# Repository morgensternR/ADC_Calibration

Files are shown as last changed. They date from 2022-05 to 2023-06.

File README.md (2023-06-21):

# ADC_Calibration
Collection/file history in making the ADC calibration board

 Copyright 2023 Ryan Morgenstern

   Licensed under the Apache License, Version 2.0 (the "License");
   you may not use this file except in compliance with the License.
   You may obtain a copy of the License at

       http://www.apache.org/licenses/LICENSE-2.0

   Unless required by applicable law or agreed to in writing, software
   distributed under the License is distributed on an "AS IS" BASIS,
   WITHOUT WARRANTIES OR CONDITIONS OF ANY KIND, either express or implied.
   See the License for the specific language governing permissions and
   limitations under the License.

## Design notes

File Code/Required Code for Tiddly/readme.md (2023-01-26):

Code for Microcontroller: 
adc_cali_board.py
diode_cali.py
MCP3421.py

Code for PC IDE:
agilent_34411a.py
Main_program.py

These Instructions assume you are following the TiddlyWiki as a reference, other hardware or Python IDE ( or no IDE) can be used to accomplish
the same task however these instructions may not assist you with that. Good Luck

Instructions:
1. Upload adc_cali_board.py, diode_cali.py, MCP3421.py to the QTPY2040. 
2. The program to run on the microcontroller is diode_cali.py (it will import the other two files you uploaded).
3. If using a python IDE (I used spyder), make sure agilent_34411a.py and Main_program.py are located in the same folder. 
	if an error occurs running the script (such as can't find import), make sure to set the console working directory to be the same as Main_program.py 
	(EX: With Main_progam.py opened in spyder, right click the top tab labeled with the file name and click 'set console working directory)
	You may also need to change the COM port...Either use device manager on windows or check it in Thonny when you connect the device...
4. Assuming everything is wired correctly for taking a short measurement, run short_measure() in Main_program.py. This will output 3 (4 outputs) measurements. 
	[[ADC integer, ADC Voltage], DMM voltage, DMM voltage reversed polarity]. 
5. Assuming everything is wired correctly for to the ADC_Calibrator board.
	Input previous short_measure() values into Calibrate(first DMM reading, second dmm reading, adc integer, and adc voltage). Run code.
6. Output format is [adc_array, dmm_0,dmm_1, dmm_c, pre_diff, post_diff, voltage, lin_info]

Explanation of output format:

adc_array = ADC integer & voltage output (non-corrected)

dmm_0 = DMM measurement of short or resistor

dmm_1 = DMM measurement of short or resistor reversed polarity

dmm_c = corrected DMM measurement without offsets ( abs(dmm_0) + abs(dmm_1) ) / 2 = dmm_c

lin_info = Linear fit to X axis being the dmm_c measurements, and Y axis is adc_array[adc integer]. We want the ADC's integer output to match the correct voltage.
	Contains slope and offset

voltage = slope and offset taken from lin_info using y = mx + b, adc_integer = adc_voltage_output * slope + offset. adc_voltage_output = (adc_int - offset)/slope

pre_diff = dmm_c - adc_array[voltage output], to see the difference a pre corrected

post_diff = dmm_c - voltage, to see the difference post corrected

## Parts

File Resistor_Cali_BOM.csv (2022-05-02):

Comment | Designator | Footprint | LCSC
Conn_Coaxial | J1 | Connector:SMA-TH_BWSMA-KE-Z001 | C496549
DB9_Female | J2 | Connector:DB9_ASSMANN | C75749
Conn_01x20_Female | J3,J4 | Connector_PinSocket_2.54mm:PinSocket_1x20_P2.54mm_Vertical
Conn_01x16_Female | J5 | Connector_PinHeader_2.54mm:PinHeader_1x16_P2.54mm_Vertical
Conn_01x01_Female | J6 | Connector_PinSocket_2.54mm:PinSocket_1x01_P2.54mm_Horizontal
1K_1% | R1,R2,R3,R4,R5,R6,R7,R15,R16,R19,R20,R21,R22,R23,R24,R25,R33,R34 | Resistor_SMD:R0603 | C234341
120K_0.1% | R10,R28 | Resistor_SMD:R0603 | C136959
130K_0.1% | R11,R29 | Resistor_SMD:R0603 | C705808
140K_0.1% | R12,R30 | Resistor_SMD:R0603 | C326761
150K_0.1% | R13,R31 | Resistor_SMD:150K_0.1 | C413715
160K_0.1% | R14,R32 | Resistor_SMD:160K_0.1 | C473318
180K_0.1% | R17,R35 | Resistor_SMD:180K_0.1 | C473319
200K_0.1% | R18,R36 | Resistor_SMD:R0603 | C394540
100K_0.1% | R8,R26 | Resistor_SMD:R0603 | C335088
110K_0.1% | R9,R27 | Resistor_SMD:R0603 | C326736
J2 | DB9_Female | DB9_ASSMANN | -63.575000 | -14.180000 | 270.000000 | top
KAQY212S | U1,U2,U3,U4,U5,U6,U7,U8,U9,U10,U11,U12,U13,U14,U15,U16,U17,U18 | Connector:SOP-4_L4.4-W4.0-P2.54-LS7.0-BL | C194898

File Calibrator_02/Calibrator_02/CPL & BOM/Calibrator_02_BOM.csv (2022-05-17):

Comment | Designator | Footprint | LCSC
1uF | C1 | Capacitor_SMD:C_0402_1005Metric | C77009
LED | D1,D2,D3,D4,D5,D6,D7,D8 | 0_Resistor_02:LED0603-RD | C125093
Conn_01x04 | J1,J6 | Connector_JST:JST_SH_SM04B-SRSS-TB_1x04-1MP_P1.00mm_Horizontal | C371571
DB9_Female_MountingHoles | J2 | 0_Resistor_02:DSUB-TH_DMR-9S | C141882
Conn_Coaxial | J3 | Connector_Coaxial:SMA_Amphenol_901-144_Vertical
Conn_01x01_Female | J5 | Connector_PinSocket_2.54mm:PinSocket_1x01_P2.54mm_Horizontal
Jumper | JP1 | Jumper:SolderJumper-2_P1.3mm_Open_RoundedPad1.0x1.5mm
AW9523BTQR | M1 | 0_Resistor_02:TQFN-24_L4.0-W4.0-P0.50-TL-EP | C148077
4.7K | R1,R2,R3 | Resistor_SMD:R_0805_2012Metric | C17673
95.3 1% | R10,R17,R18,R19,R20,R21,R22,R23 | Resistor_SMD:R_0201_0603Metric_Pad0.64x0.40mm_HandSolder | C218188
84.5 1% | R11,R12,R13,R14,R15,R16,R24,R25,R26,R27,R28,R29,R30,R31,R32,R33,R34,R35,R36,R37,R38,R39,R40,R41 | Resistor_SMD:R_0201_0603Metric_Pad0.64x0.40mm_HandSolder | C177824
120K_0.1% | R4 | Resistor_SMD:R_0603_1608Metric_Pad0.98x0.95mm_HandSolder | C136959
140K_0.1% | R5 | Resistor_SMD:R_0603_1608Metric_Pad0.98x0.95mm_HandSolder | C326761
160K_0.1% | R6 | Resistor_SMD:R_0805_2012Metric_Pad1.20x1.40mm_HandSolder | C473318
180K_0.1% | R7 | Resistor_SMD:R_0805_2012Metric_Pad1.20x1.40mm_HandSolder | C473319
100K_0.1% | R8 | Resistor_SMD:R_0603_1608Metric_Pad0.98x0.95mm_HandSolder | C335088
200K_0.1% | R9 | Resistor_SMD:R_0603_1608Metric_Pad0.98x0.95mm_HandSolder | C394540
KAQY214STLD | U1,U2,U3,U4,U5,U6,U7,U8,U9,U10,U11,U12,U13,U14,U15,U16,U17,U18,U19,U20,U21,U22,U23,U24,U25,U26,U27,U28,U29,U30,U31,U32 | 0_Resistor_02:SOP-4_L3.9-W4.4-P2.54-LS7.0-BR | C113331

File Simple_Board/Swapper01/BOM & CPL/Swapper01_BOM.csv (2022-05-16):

Comment | Designator | Footprint | LCSC
DB9_Female_MountingHoles | J1 | 0_Swapper01:DSUB-TH_DMR-9S | C141882
Conn_01x04 | J2 | Connector_JST:JST_SH_SM04B-SRSS-TB_1x04-1MP_P1.00mm_Horizontal
Jumper | JP1,JP2,JP3,JP4,JP5,JP6,JP7,JP8,JP9,JP10,JP11,JP12,JP13,JP14,JP15,JP16,JP17,JP18,JP19,JP20,JP21,JP22,JP23,JP24 | Jumper:SolderJumper-2_P1.3mm_Open_RoundedPad1.0x1.5mm
Jumper_3_Open | JP25,JP26,JP27,JP28 | Jumper:SolderJumper-3_P1.3mm_Open_Pad1.0x1.5mm
100K | R1 | Resistor_SMD:R_0603_1608Metric_Pad0.98x0.95mm_HandSolder | C335088
120K | R2 | Resistor_SMD:R_0603_1608Metric_Pad0.98x0.95mm_HandSolder | C136959
140K | R3 | Resistor_SMD:R_0603_1608Metric_Pad0.98x0.95mm_HandSolder | C326761
160K | R4 | Resistor_SMD:R_0805_2012Metric_Pad1.20x1.40mm_HandSolder | C473318
180K | R5 | Resistor_SMD:R_0805_2012Metric_Pad1.20x1.40mm_HandSolder | C473319
200K | R6 | Resistor_SMD:R_0603_1608Metric_Pad0.98x0.95mm_HandSolder | C394540

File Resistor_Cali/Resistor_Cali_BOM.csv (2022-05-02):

Id | Designator | Package | Quantity | Designation | Supplier and ref
1 | J1 | SMA-TH_BWSMA-KE-Z001 | 1 | Conn_Coaxial
2 | U16,U15,U7,U14,U6,U13,U18,U5,U12,U4,U17,U11,U3,U10,U9,U2,U8,U1 | SOP-4_L4.4-W4.0-P2.54-LS7.0-BL | 18 | KAQY212S
3 | R25,R24,R7,R23,R6,R22,R34,R5,R21,R4,R33,R20,R3,R19,R16,R2,R15,R1 | R0603 | 18 | 1K_1%
4 | R32,R14 | 160K_0.1 | 2 | 160K_0.1%
5 | R31,R13 | 150K_0.1 | 2 | 150K_0.1%
6 | R30,R12 | R0603 | 2 | 140K_0.1%
7 | R29,R11 | R0603 | 2 | 130K_0.1%
8 | R36,R18 | R0603 | 2 | 200K_0.1%
9 | R28,R10 | R0603 | 2 | 120K_0.1%
10 | R35,R17 | 180K_0.1 | 2 | 180K_0.1%
11 | R27,R9 | R0603 | 2 | 110K_0.1%
12 | R26,R8 | R0603 | 2 | 100K_0.1%
13 | J5 | PinHeader_1x16_P2.54mm_Vertical | 1 | Conn_01x16_Female
14 | J4,J3 | PinSocket_1x20_P2.54mm_Vertical | 2 | Conn_01x20_Female
15 | J2 | DB9_ASSMANN | 1 | DB9_Female
16 | J6 | PinSocket_1x01_P2.54mm_Horizontal | 1 | Conn_01x01_Female

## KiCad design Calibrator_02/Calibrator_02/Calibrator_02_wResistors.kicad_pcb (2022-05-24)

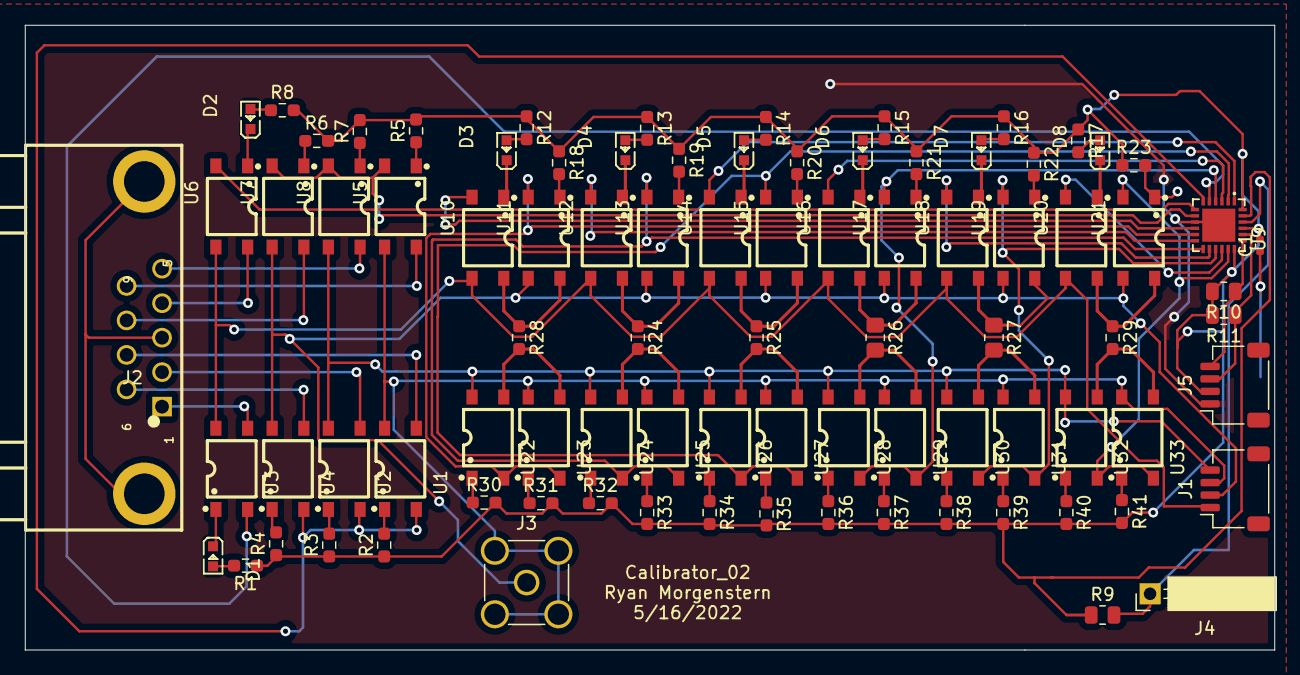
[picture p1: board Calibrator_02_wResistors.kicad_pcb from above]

Board: 2 copper layers, 100.0 x 50.0 mm, 88 parts (0 on the bottom side), 86 nets.

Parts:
C1: 100nF; C_0402_1005Metric
D1, D2, D3, D4, D5, D6, D7, D8: LED; LED0603-RD
J1, J5: Conn_01x04; JST_SH_SM04B-SRSS-TB_1x04-1MP_P1.00mm_Horizontal
J2: DB9_Female_MountingHoles; DSUB-TH_DMR-9S
J3: Conn_Coaxial; SMA_Amphenol_901-144_Vertical
J4: Conn_01x01_Female; PinSocket_1x01_P2.54mm_Horizontal
R1, R8, R12, R13, R14, R15, R16, R17: 95.3 1%; R_0603_1608Metric_Pad0.98x0.95mm_HandSolder
R2, R3, R4, R5, R6, R7, R18, R19, R20, R21, R22, R23, R30, R31, R32, R33, R34, R35, R36, R37, R38, R39, R40, R41: 84.5 1%; R_0603_1608Metric_Pad0.98x0.95mm_HandSolder
R9, R10, R11: 4.7K; R_0805_2012Metric
R24: 120K_0.1%; R_0603_1608Metric_Pad0.98x0.95mm_HandSolder
R25: 140K_0.1%; R_0603_1608Metric_Pad0.98x0.95mm_HandSolder
R26: 160K_0.1%; R_0805_2012Metric_Pad1.20x1.40mm_HandSolder
R27: 180K_0.1%; R_0805_2012Metric_Pad1.20x1.40mm_HandSolder
R28: 100K_0.1%; R_0603_1608Metric_Pad0.98x0.95mm_HandSolder
R29: 200K_0.1%; R_0603_1608Metric_Pad0.98x0.95mm_HandSolder
U1, U2, U3, U4, U5, U6, U7, U8, U10, U11, U12, U13, U14, U15, U16, U17, U18, U19, U20, U21, U22, U23, U24, U25, U26, U27, U28, U29, U30, U31, U32, U33: KAQY214STLD; SOP-4_L3.9-W4.4-P2.54-LS7.0-BR
U9: AW9523BTQR; TQFN-24_L4.0-W4.0-P0.50-TL-EP

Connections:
+3V3: C1.2, J5.2, R1.1, R2.1, R3.1, R4.1, R5.2, R6.2, R7.2, R8.2, R9.1, R10.2, R11.2, R12.1, R13.1, R14.1, R15.1, R16.1, R17.1, R18.1, R19.1, R20.1, R21.1, R22.1, R23.1, R30.2, R31.2, R32.2, R33.2, R34.2, R35.2, R36.2, R37.2, R38.2, R39.2, R40.2, R41.2, U9.18, U9.21, U9.23, U9.24
/I+: J2.1, U3.3
/I-: J2.2, U2.3
/I_00: U3.2, U9.5
/I_01: U1.2, U2.2, U4.2, U9.6
/I_02: U6.2, U9.7
/I_2+: J2.4, U6.4
/I_2-: J2.5, U8.4
/I_03: U5.2, U7.2, U8.2, U9.8
/I_04: U9.10, U10.2
/I_05: U9.11, U11.2, U22.2, U23.2
/I_06: U9.12, U12.2
/I_07: U9.13, U13.2, U24.2, U25.2
/I_10: U9.1, U14.2
/I_11: U9.2, U15.2, U26.2, U27.2
/I_12: U9.3, U16.2
/I_13: U9.4, U17.2, U28.2, U29.2
/I_14: U9.14, U18.2
/I_15: U9.15, U19.2, U30.2, U31.2
/I_16: U9.16, U20.2
/I_17: U9.17, U21.2, U32.2, U33.2
/Resistor_Network/I+: J1.1, U3.4, U6.3, U10.3, U12.3, U14.3, U16.3, U18.3, U20.3
/Resistor_Network/I-: J1.4, U2.4, U8.3, U22.4, U24.4, U26.4, U28.4, U30.4, U32.4
/Resistor_Network/V+: J1.2, J3.1, U4.4, U7.3, U11.3, U13.3, U15.3, U17.3, U19.3, U21.3
/Resistor_Network/V-: J1.3, J3.2, U1.4, U5.3, U23.4, U25.4, U27.4, U29.4, U31.4, U33.4
/V+: J2.6, U4.3
/V-: J2.7, U1.3
/V_2+: J2.8, U7.4
/V_2-: J2.9, U5.4
GND: C1.1, J5.1, U9.9, U9.25
GNDS: J2.0, J2.3
unnamed: D1.1, U3.1
unnamed: D1.2, R1.2
unnamed: D2.1, U6.1
unnamed: D2.2, R8.1
unnamed: D3.1, U10.1
unnamed: D3.2, R12.2
unnamed: D4.1, U12.1
unnamed: D4.2, R13.2
unnamed: D5.1, U14.1
unnamed: D5.2, R14.2
unnamed: D6.1, U16.1
unnamed: D6.2, R15.2
unnamed: D7.1, U18.1
unnamed: D7.2, R16.2
unnamed: D8.1, U20.1
unnamed: D8.2, R17.2
unnamed: J4.1, R9.2, U9.22
unnamed: J5.3, R11.1, U9.20
unnamed: J5.4, R10.1, U9.19
unnamed: R2.2, U1.1
unnamed: R3.2, U2.1
unnamed: R4.2, U4.1
unnamed: R5.1, U5.1
unnamed: R6.1, U7.1
unnamed: R7.1, U8.1
unnamed: R18.2, U11.1
unnamed: R19.2, U13.1
unnamed: R20.2, U15.1
unnamed: R21.2, U17.1
unnamed: R22.2, U19.1
unnamed: R23.2, U21.1
unnamed: R24.1, U12.4, U13.4
unnamed: R24.2, U24.3, U25.3
unnamed: R25.1, U14.4, U15.4
unnamed: R25.2, U26.3, U27.3
unnamed: R26.1, U16.4, U17.4
unnamed: R26.2, U28.3, U29.3
unnamed: R27.1, U18.4, U19.4
unnamed: R27.2, U30.3, U31.3
unnamed: R28.1, U10.4, U11.4
unnamed: R28.2, U22.3, U23.3
unnamed: R29.1, U20.4, U21.4
unnamed: R29.2, U32.3, U33.3
unnamed: R30.1, U22.1
unnamed: R31.1, U23.1
unnamed: R32.1, U24.1
unnamed: R33.1, U25.1
unnamed: R34.1, U26.1
unnamed: R35.1, U27.1
unnamed: R36.1, U28.1
unnamed: R37.1, U29.1
unnamed: R38.1, U30.1
unnamed: R39.1, U31.1
unnamed: R40.1, U32.1
unnamed: R41.1, U33.1

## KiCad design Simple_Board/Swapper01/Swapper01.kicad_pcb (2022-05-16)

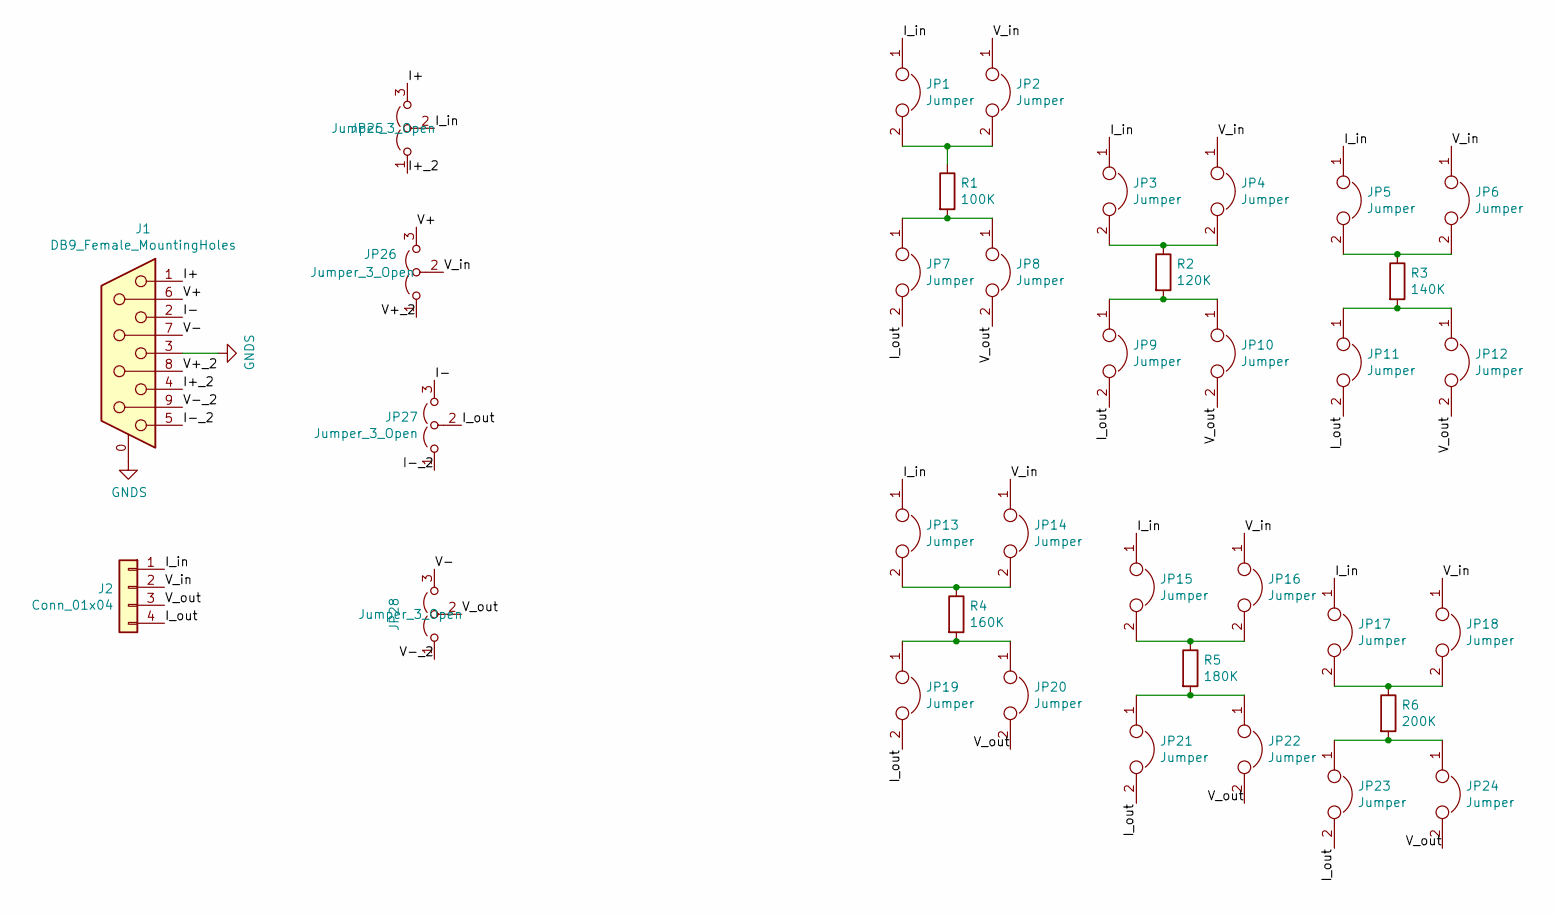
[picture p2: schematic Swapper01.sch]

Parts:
J1: DB9_Female_MountingHoles; DSUB-TH_DMR-9S; LCSC C141882
J2: Conn_01x04; JST_SH_SM04B-SRSS-TB_1x04-1MP_P1.00mm_Horizontal
JP1, JP2, JP3, JP4, JP5, JP6, JP7, JP8, JP9, JP10, JP11, JP12, JP13, JP14, JP15, JP16, JP17, JP18, JP19, JP20, JP21, JP22, JP23, JP24: Jumper; SolderJumper-2_P1.3mm_Open_RoundedPad1.0x1.5mm
JP25, JP26, JP27, JP28: Jumper_3_Open; SolderJumper-3_P1.3mm_Open_Pad1.0x1.5mm
R1: 100K; R_0603_1608Metric_Pad0.98x0.95mm_HandSolder; LCSC C335088
R2: 120K; R_0603_1608Metric_Pad0.98x0.95mm_HandSolder; LCSC C136959
R3: 140K; R_0603_1608Metric_Pad0.98x0.95mm_HandSolder; LCSC C326761
R4: 160K; R_0805_2012Metric_Pad1.20x1.40mm_HandSolder; LCSC C473318
R5: 180K; R_0805_2012Metric_Pad1.20x1.40mm_HandSolder; LCSC C473319
R6: 200K; R_0603_1608Metric_Pad0.98x0.95mm_HandSolder; LCSC C394540

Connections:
/I+: J1.1, JP25.3 (B)
/I+_2: J1.4, JP25.1 (A)
/I-: J1.2, JP27.3 (B)
/I-_2: J1.5, JP27.1 (A)
/I_in: J2.1, JP1.1, JP3.1, JP5.1, JP13.1, JP15.1, JP17.1, JP25.2 (C)
/I_out: J2.4, JP7.2, JP9.2, JP11.2, JP19.2, JP21.2, JP23.2, JP27.2 (C)
/V+: J1.6, JP26.3 (B)
/V+_2: J1.8, JP26.1 (A)
/V-: J1.7, JP28.3 (B)
/V-_2: J1.9, JP28.1 (A)
/V_in: J2.2, JP2.1, JP4.1, JP6.1, JP14.1, JP16.1, JP18.1, JP26.2 (C)
/V_out: J2.3, JP8.2, JP10.2, JP12.2, JP20.2, JP22.2, JP24.2, JP28.2 (C)
GNDS: J1.0 (PAD), J1.3
unnamed: JP1.2, JP2.2, R1.1
unnamed: JP3.2, JP4.2, R2.1
unnamed: JP5.2, JP6.2, R3.1
unnamed: JP7.1, JP8.1, R1.2
unnamed: JP9.1, JP10.1, R2.2
unnamed: JP11.1, JP12.1, R3.2
unnamed: JP13.2, JP14.2, R4.1
unnamed: JP15.2, JP16.2, R5.1
unnamed: JP17.2, JP18.2, R6.1
unnamed: JP19.1, JP20.1, R4.2
unnamed: JP21.1, JP22.1, R5.2
unnamed: JP23.1, JP24.1, R6.2

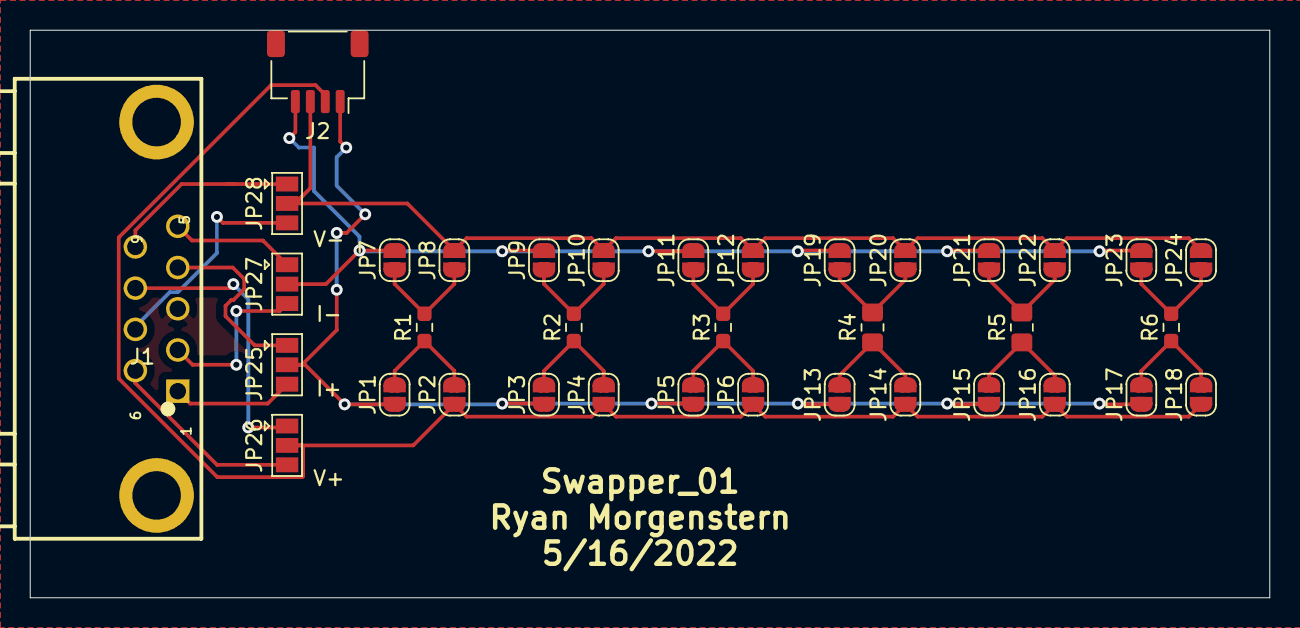
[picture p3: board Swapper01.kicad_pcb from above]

Board: 2 copper layers, 83.0 x 38.0 mm, 36 parts (0 on the bottom side), 24 nets.

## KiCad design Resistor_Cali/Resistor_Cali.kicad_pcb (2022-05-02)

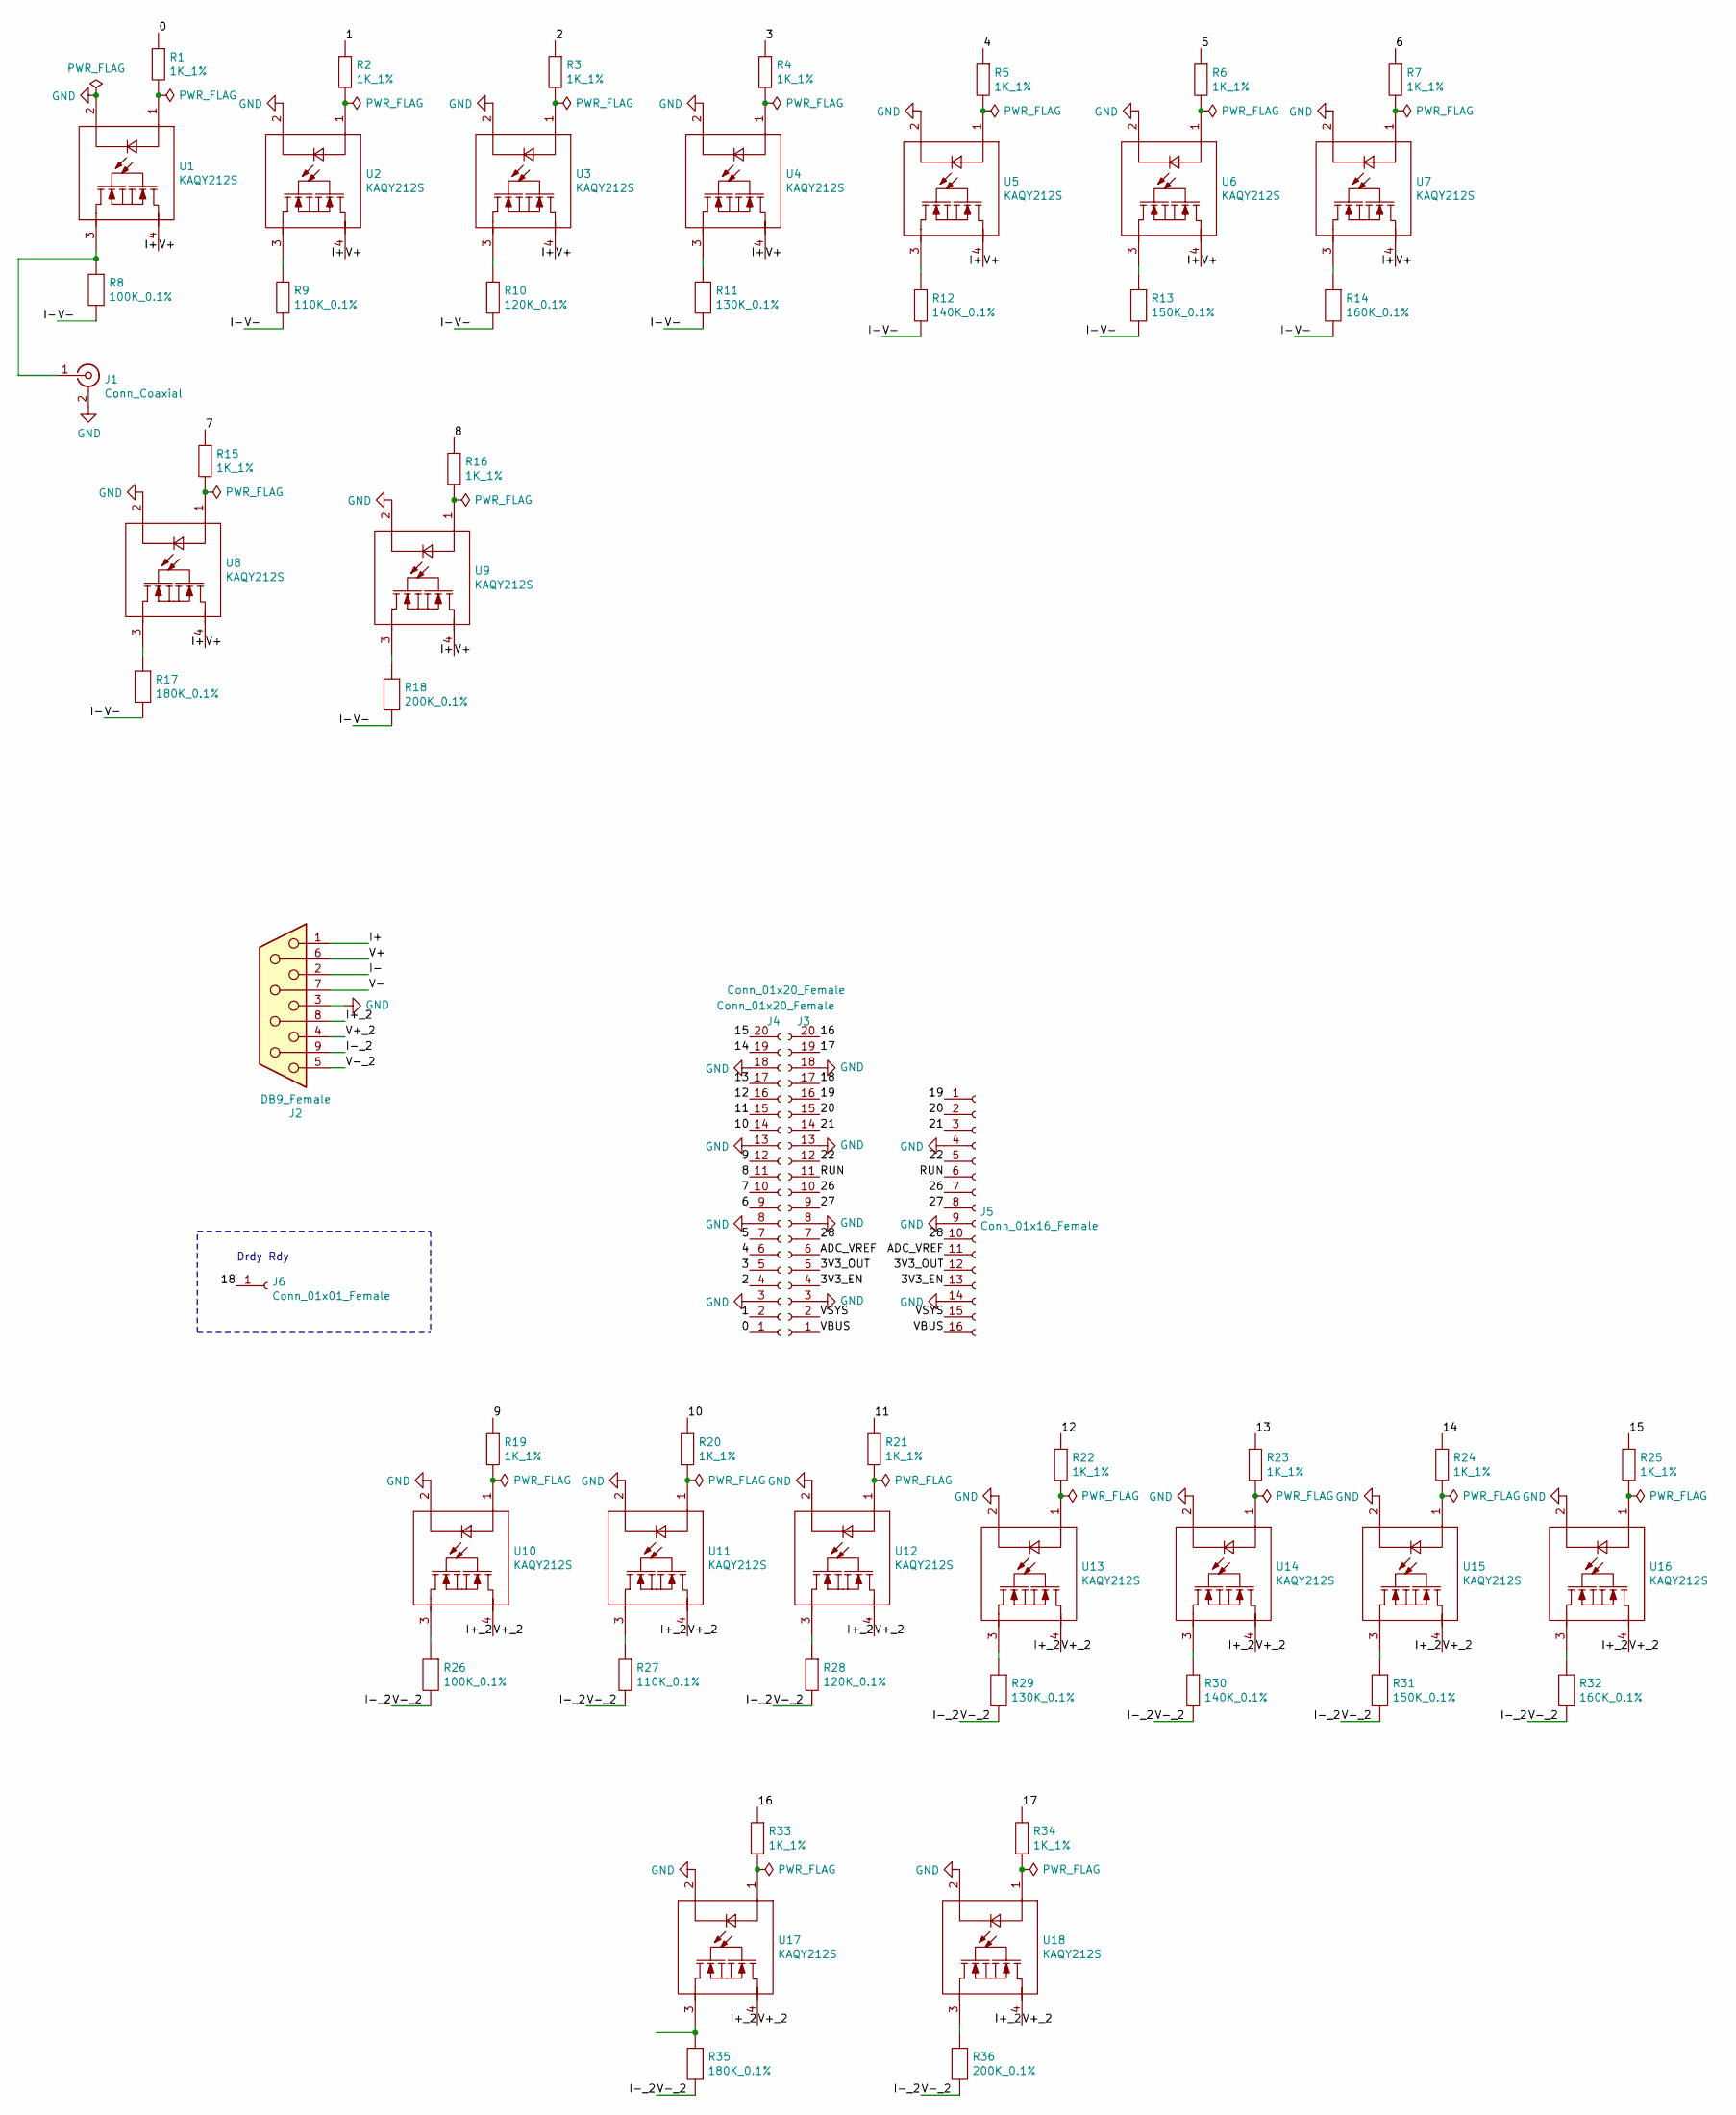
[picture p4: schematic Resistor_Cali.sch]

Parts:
J1: Conn_Coaxial; SMA-TH_BWSMA-KE-Z001; LCSC C496549
J2: DB9_Female; DB9_ASSMANN; LCSC C75749
J3, J4: Conn_01x20_Female; PinSocket_1x20_P2.54mm_Vertical
J5: Conn_01x16_Female; PinHeader_1x16_P2.54mm_Vertical
J6: Conn_01x01_Female; PinSocket_1x01_P2.54mm_Horizontal
R1, R2, R3, R4, R5, R6, R7, R15, R16, R19, R20, R21, R22, R23, R24, R25, R33, R34: 1K_1%; R0603; LCSC C328340
R8, R26: 100K_0.1%; R0603; LCSC C335088
R9, R27: 110K_0.1%; R0603; LCSC C326736
R10, R28: 120K_0.1%; R0603; LCSC C136959
R11, R29: 130K_0.1%; R0603; LCSC C705808
R12, R30: 140K_0.1%; R0603; LCSC C326761
R13, R31: 150K_0.1%; 150K_0.1; LCSC C413715
R14, R32: 160K_0.1%; 160K_0.1; LCSC C473318
R17, R35: 180K_0.1%; 180K_0.1; LCSC C473319
R18, R36: 200K_0.1%; R0603; LCSC C394540
U1, U2, U3, U4, U5, U6, U7, U8, U9, U10, U11, U12, U13, U14, U15, U16, U17, U18: KAQY212S; SOP-4_L4.4-W4.0-P2.54-LS7.0-BL; LCSC C194898

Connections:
/0: J3.1, R1.1
/1: J3.2, R2.1
/2: J3.4, R3.1
/3: J3.5, R4.1
/3V3_EN: J4.4, J5.13
/3V3_OUT: J4.5, J5.12
/4: J3.6, R5.1
/5: J3.7, R6.1
/6: J3.9, R7.1
/7: J3.10, R15.1
/8: J3.11, R16.1
/9: J3.12, R19.1
/10: J3.14, R20.1
/11: J3.15, R21.1
/12: J3.16, R22.1
/13: J3.17, R23.1
/14: J3.19, R24.1
/15: J3.20, R25.1
/16: J4.20, R33.1
/17: J4.19, R34.1
/18: J4.17, J6.1
/19: J4.16, J5.1
/20: J4.15, J5.2
/21: J4.14, J5.3
/22: J4.12, J5.5
/26: J4.10, J5.7
/27: J4.9, J5.8
/28: J4.7, J5.10
/ADC_VREF: J4.6, J5.11
/I+: J2.1, J2.6, U1.4, U2.4, U3.4, U4.4, U5.4, U6.4, U7.4, U8.4, U9.4
/I+_2: J2.4, J2.8, U10.4, U11.4, U12.4, U13.4, U14.4, U15.4, U16.4, U17.4, U18.4
/I-: J2.2, J2.7, R8.2, R9.2, R10.2, R11.2, R12.2, R13.2, R14.2, R17.2, R18.2
/I-_2: J2.5, J2.9, R26.2, R27.2, R28.2, R29.2, R30.2, R31.2, R32.2, R35.2, R36.2
/RUN: J4.11, J5.6
/VBUS: J4.1, J5.16
/VSYS: J4.2, J5.15
GND: J1.2 (Ext), J2.0, J2.3, J3.3, J3.8, J3.13, J3.18, J4.3, J4.8, J4.13, J4.18, J5.4, J5.9, J5.14, U1.2, U2.2, U3.2, U4.2, U5.2, U6.2, U7.2, U8.2, U9.2, U10.2, U11.2, U12.2, U13.2, U14.2, U15.2, U16.2, U17.2, U18.2
unnamed: J1.1 (In), R8.1, U1.3
unnamed: R1.2, U1.1
unnamed: R2.2, U2.1
unnamed: R3.2, U3.1
unnamed: R4.2, U4.1
unnamed: R5.2, U5.1
unnamed: R6.2, U6.1
unnamed: R7.2, U7.1
unnamed: R9.1, U2.3
unnamed: R10.1, U3.3
unnamed: R11.1, U4.3
unnamed: R12.1, U5.3
unnamed: R13.1, U6.3
unnamed: R14.1, U7.3
unnamed: R15.2, U8.1
unnamed: R16.2, U9.1
unnamed: R17.1, U8.3
unnamed: R18.1, U9.3
unnamed: R19.2, U10.1
unnamed: R20.2, U11.1
unnamed: R21.2, U12.1
unnamed: R22.2, U13.1
unnamed: R23.2, U14.1
unnamed: R24.2, U15.1
unnamed: R25.2, U16.1
unnamed: R26.1, U10.3
unnamed: R27.1, U11.3
unnamed: R28.1, U12.3
unnamed: R29.1, U13.3
unnamed: R30.1, U14.3
unnamed: R31.1, U15.3
unnamed: R32.1, U16.3
unnamed: R33.2, U17.1
unnamed: R34.2, U18.1
unnamed: R35.1, U17.3
unnamed: R36.1, U18.3

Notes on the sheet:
Drdy Rdy

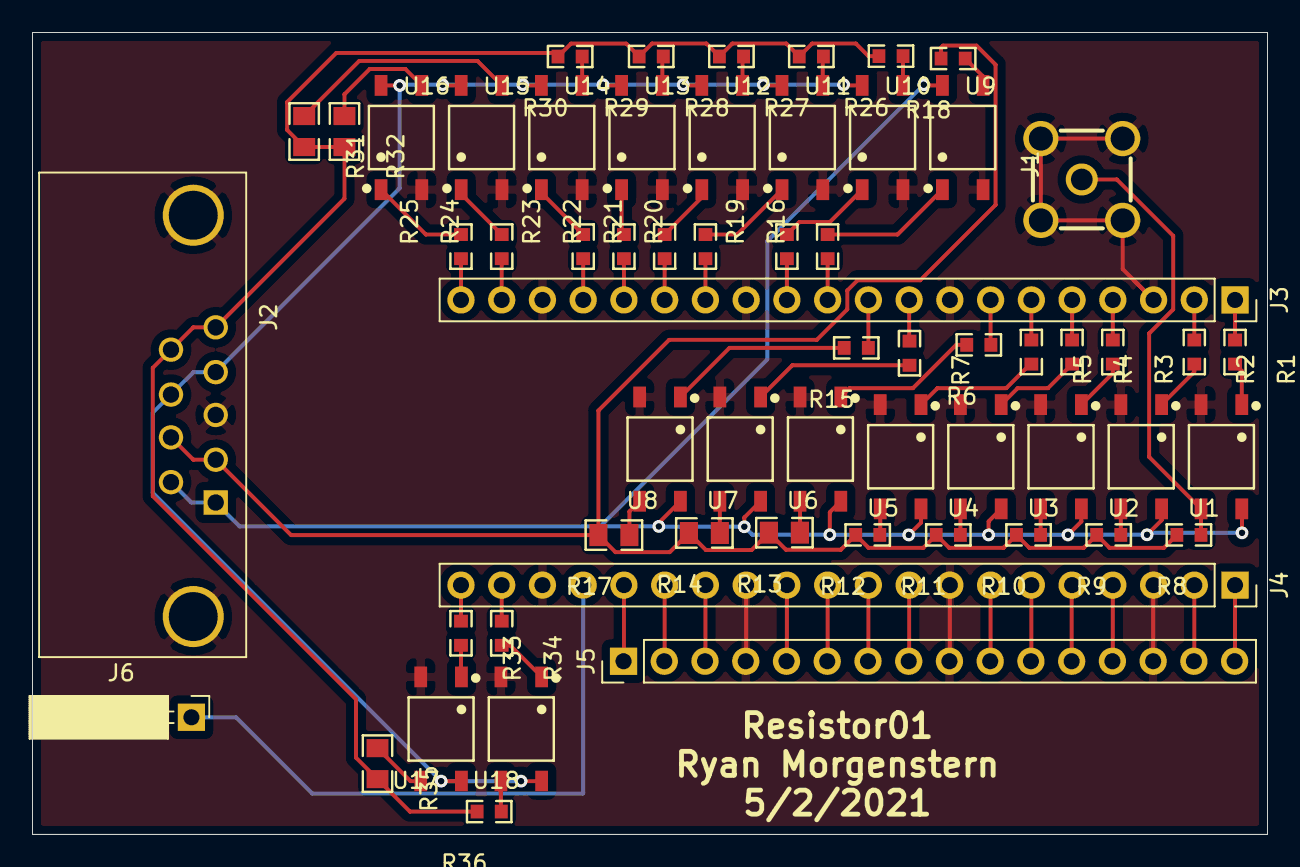
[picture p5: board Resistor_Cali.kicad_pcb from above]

Board: 2 copper layers, 77.0 x 50.0 mm, 60 parts (0 on the bottom side), 73 nets.

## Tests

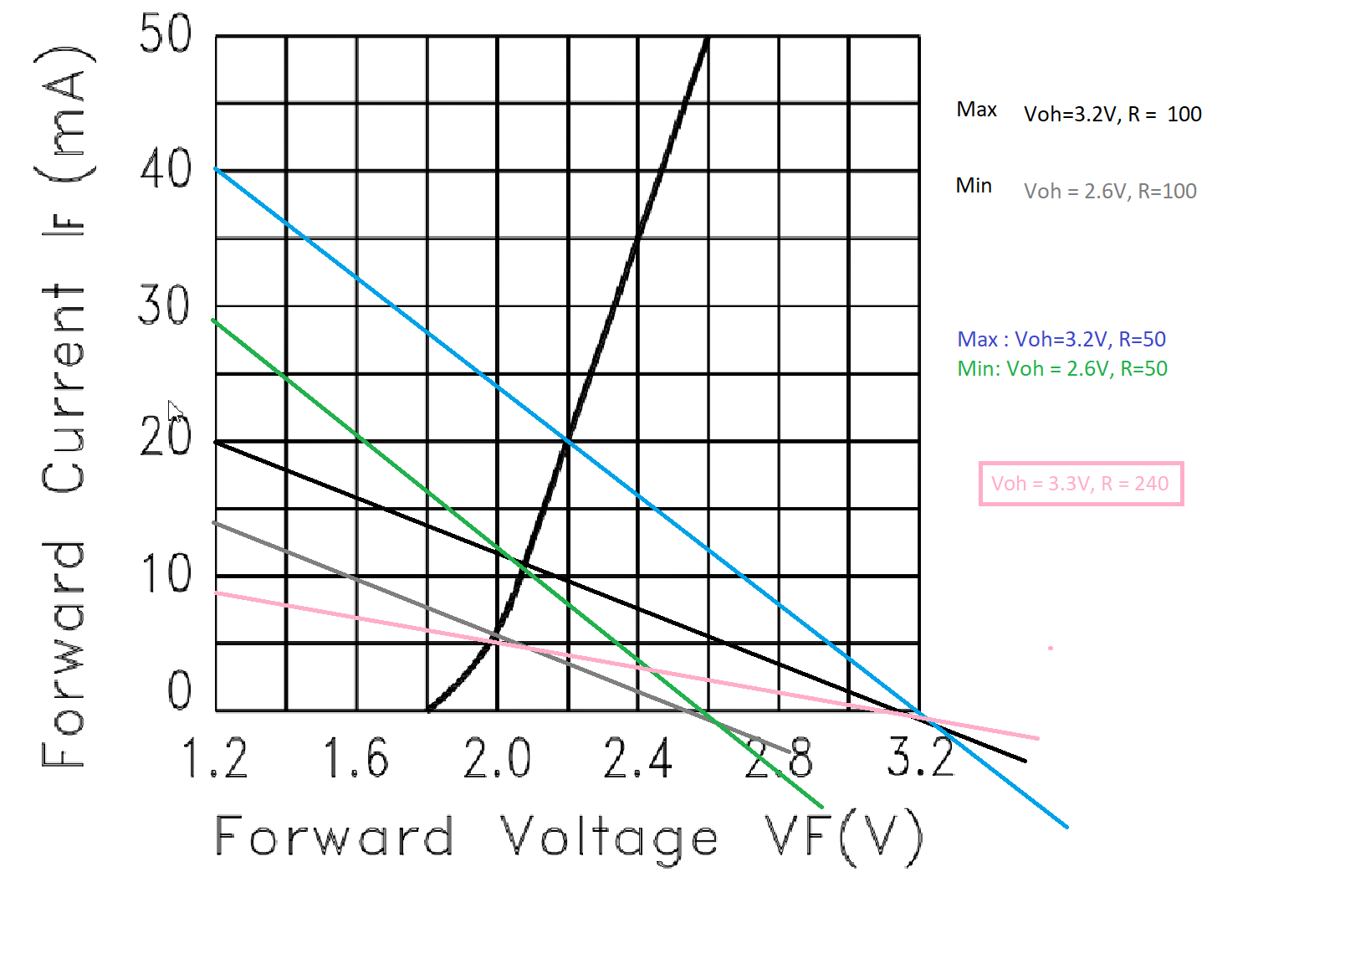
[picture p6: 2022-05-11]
Calibrator_02/Calibrator_02/LED_Current_Graph.png

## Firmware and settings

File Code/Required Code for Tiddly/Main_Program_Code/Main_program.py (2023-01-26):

#%%

#Diode Calibration Code, Uses Serial to write/read from qtpy and also communicate from dmm

import numpy as np
import time
import serial
from scipy.stats import linregress
import agilent_34411a as dmm
#port.close()
device = dmm.Agilent34411A('USB0::0x0957::0x0A07::MY46000585::INSTR')
port = serial.Serial('COM9', timeout=1)

def short_measure():
    dmm_0 = []
    dmm_1 = []
    adc = []
    
    device.NPLC(100)
    device.res_auto()
    time.sleep(0.1)
    port.write(b'switch 0\n')
    for i in range(30):  #adjust till lowest int...
        port.write(b'read\n')
        print(port.readlines())
        time.sleep(0.1)
        
        
    port.write(b'read\n')
    line = port.readlines()
    adc.append([line[0].decode().strip(), line[1].decode().strip()])
    dmm_0.append(device.read_())
    
    port.write(b'switch\n')
    dmm_1.append(device.read_())
    port.write(b'switch\n')
    return adc, dmm_0, dmm_1
    
    
def Calibrate(dmm_short0, dmm_short1, adc_short_int, adc_short_v):
    dmm_0 = [dmm_short0]
    dmm_1 = [dmm_short1]
    dmm_c = []
    adc = [[adc_short_int, adc_short_v]]
    pre_diff = []
    post_diff =[]
    res_list = [100,120,140,160,180]
    device.NPLC(100)
    device.res_auto()
    port.write(b'switch 0\n')
    for i in res_list:
        #Switch to IK, get 1 reading from ADC, get 1 reading from dmm, switch, then get othe reading from dmm
        port.write(bytes('{0}K\n'.format(i), encoding = 'utf-8'))
        time.sleep(0.1)
        for i in range(5):
                    port.write(b'read\n')
                    print(port.readlines())
        port.write(b'read\n')
        line = port.readlines()
        adc.append([line[0].decode().strip(), line[1].decode().strip()])
        dmm_0.append(device.read_())
        
        port.write(b'switch\n')
        dmm_1.append(device.read_())
        port.write(b'switch\n')
        
    adc_array = np.array(adc).astype(float)
    for i in range(len(dmm_0)):
        dmm_c.append( (abs(dmm_0[i]) + abs(dmm_1[i])) /2)
        pre_diff.append(round((dmm_c[i] - adc_array[i, 1]), 7)*1e3) #convert to mV
    
    lin_info = linregress(dmm_c, adc_array[:,0]) #Find slope and intercept of output codes wrt actual voltage
    
    voltage =  (adc_array[:, 0] - int(lin_info[1])) / lin_info[0] 

    for i in range(len(dmm_c)):
        post_diff.append(round(dmm_c[i]- voltage[i], 7)*1e3)
    return adc_array, dmm_0,dmm_1, dmm_c, pre_diff, post_diff, voltage, lin_info

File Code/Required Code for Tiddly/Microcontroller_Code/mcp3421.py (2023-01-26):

from machine import Pin, I2C
import time
from math import ceil
from uctypes import BF_POS, BF_LEN, UINT32, BFUINT8, addressof, struct




class MCP3421:
    def __init__(self, i2c, sampling = 2, gain = 0, conversion = 1, slope = 16000, offset = 0,  addr=104):#out_port, A_port, B_port,
        self.i2c = i2c
        self.addr = addr
        
        bits_list = [12, 14, 16, 18]
        self.bits = bits_list[sampling]

        self.slope = slope
        if self.slope == 16000: #default is 16K, if bits are set other than 16, it adjusts, or make it calibrated slope
            self.slope = (2**(self.bits - 1))/2.048
        self.offset = offset
        

        self.data_size = ceil(self.bits/8)
        
        #conversion = 1 = Continous
        #conversion = 0 = one-shot
        #Sampling
        # 0  = 240 SPS 12 bits
        # 1  = 60 SPS 14 bits
        # 2  = 15 SPS 16 bits
        # 3  = 3.75 SPS 18 bits
        self.register_fields = {
                "dataready": 7<<BF_POS | 1 <<BF_LEN | BFUINT8,
                "unused"   : 5<<BF_POS | 2 <<BF_LEN | BFUINT8,
                "mode"     : 4<<BF_POS | 1 <<BF_LEN | BFUINT8,
                "sampling" : 2<<BF_POS | 2 <<BF_LEN | BFUINT8,
                "gain"     : 0<<BF_POS | 2 <<BF_LEN | BFUINT8,
            }

        self.register_buffer = bytearray(1)
        self.register = struct(addressof(self.register_buffer), self.register_fields)
        
        self.register.gain = gain
        self.register.mode = conversion
        self.register.sampling = sampling
        
        self.set_config()
        self.read_config()
        
    def set_config(self):
        #Constructs message by 'or'ing numbers together
        #register_value = (self.conversion << 4) | (self.bit_dict[self.bits] << 3) | (self.gain_dict[self.gain])
        self.i2c.writeto(self.addr, bytes([self.register_buffer[0]]))
        
    def read_config(self):
        #Adc attches config at end of data bits. Requires minumum bytes for bits + 1 for config byte
        data = bytearray(self.data_size + 1)
        
        self.i2c.readfrom_into(self.addr, data)
        self.register_buffer[0] = data[-1]
        #returns last byte in array which is config
        return self.register_buffer[0]
    
    def drdy(self):
        while (self.read_config() >> 7 ) == 1:
            pass
        
    def read_adc(self):
        data = bytearray(self.data_size)
        self.drdy() #Determines when to read depending on data Rdy Bit
        self.i2c.readfrom_into(self.addr, data)
        #Int from bytes can convert sign for multiples of bytes but not bits.Ex Can use Signed True on 8,16,24 bits (1,2,3 bytes)
        result = int.from_bytes(data[:self.data_size],'big')
        
        if result & ( 1 << ( self.bits-1 )):
            result = result - ( 1 << self.bits )
        
        return result
    
    def read_adc_v(self):
        adc_int = self.read_adc()
        result = (adc_int - self.offset)/(self.slope * (2**self.register.gain))
        return result
    
#Code below is for testing
'''
i2c = I2C(1, scl=Pin(23, Pin.PULL_UP), sda=Pin(22, Pin.PULL_UP))
dev = MCP3421(i2c, sampling = 2, conversion = 1, gain = 0)

while True:
    print(dev.read_adc_v())
'''

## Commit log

2022-05-05 New Design
    [Resistor_02.kicad_pcb, Resistor_02.sch, Resistor_Network.sch]
2022-05-11 Update
    Nearly finished versions of simple and Calibrator board
    [Calibrator_02.kicad_pcb, Calibrator_02.sch, Resistor_Network.sch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]
2022-05-12 Removed resistor_02 bc bad name
    [Resistor_02.kicad_pcb, Resistor_02.sch, Resistor_Network.sch]
2022-05-12 Fixed jst pinouts and made Cali board
    [Calibrator_02.kicad_pcb, Calibrator_02.sch, Calibrator_02_wResistors.sch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]
2022-05-17 Added Resistors to Diodes
    [Calibrator_02-B_Cu.gbl, Calibrator_02-B_Mask.gbs, Calibrator_02-B_Paste.gbp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]
2022-05-18 Fixed footprint
    [Calibrator_02-B_Cu.gbl, Calibrator_02-B_Mask.gbs, Calibrator_02-B_Paste.gbp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]
2022-05-18 Fixed PCB Name
    [Calibrator_02_wResistors.kicad_pcb]
2022-05-18 Moved old files
    [Calibrator_02.sch]
2022-05-20 Fixed trace distance
    [Calibrator_02-B_Paste.gbp, Calibrator_02-NPTH.drl, Calibrator_02-PTH.drl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]
2023-01-26 can read adc without sleep
